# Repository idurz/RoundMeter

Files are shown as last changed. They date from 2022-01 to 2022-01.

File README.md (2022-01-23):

# RoundMeter
CO2 measurement as a learning experiment with a round LCD. The device will show succesively a (dutch) weather forecast. the CO2 measurement in the room and a (dutch) forecast for the rain amount the next 2 hours.

## PARTS USED
- Waveshare 1.28 Round LCD
- Winsen MH-Z19B CO2 sensor 
- Wemos D1 mini lite ESP8266 micro controller
- USB micro cable connected to a power source

## Information sources
Thanks to the Dutch website Buienradar.nl which has the weather conditions in JSON format and a text based rain forecast for the next 2 hours. The CO2 information is read fromt he local MHZ sensor.

**Note:** The sensor is intended for the Dutch weather forecast. You can reuse parts and ideas for the rest of the world, change urls and interpretation of the output in the way you like.

## Build
### Connect CO2 Sensor
The Winsen CO2 sensor has a break-out board. From that board you need to connect four cables to the Wemos board:
- Green (RX) to Wemos D1
- Blue (TX) to Wemos D2
- Black (Gnd) to Wemos GND _(shared with display)_
- Red (5V) to Wemos 5V _(shared with display)_

### Connect Display
The WaveShare 1.18 Inch LCD display uses a SPI interface. Connect the following wires to the Wemos board:
- Blue (DC) to Wemos D3
- Yellow (CS) to Wemos D0
- Orange (CLK) to Wemos D5
- Green (DIN) to Wemos D7
- Purple (VCC) to Wemos 3V3
- White (GND) to Wemos GND _(shared with sensor)_
- Grey (BL) to Wemos 5V _(shared with sensor)_
- Brown (RST) to Wemos D4

### The Box
The box is designed with [TinkerCad](https://www.tinkercad.com/things/4qZ85xxE9la-128-round-lcd-2). Download or change the box there, or simply download the STL file from the /box design directory.

### Software
I used Visual Studio Code with the Platform IO extension to create and upload the code to the Wemos. It will work with e.g. the Arduino editor as well, but you might need to change some library references etc.

### Localization
Check the main.ccp file. On line 178 in the variable rain_link2 the latitude and longitude of the rain forecast location is mentioned. Change to a convineant lcation.
Also on line 179 the station id is mentioned for the Weather station. If you want to know alternatives, view the [JSON info](data.buienradar.nl/2.0/feed/json) online. Change to what fits you best.

Recompile the source and upload to the Wemos.

## INSTALLATION
This device is using the wifimanager library for an initial setup in a new environment. Power up the meter the first time in a new environment and give it some moments to start up. The device will create a Wifi network with the SSID "Kippenhok".

- Go to the settings on your phone
- Select the netwerk "Kippenhok"
- Your phone will connect to the network "Kippenhok"
- A webpage will pop-up automatic
- Select "Configure Wifi" 
- Select your own network in the list
- Add the password for this network
- Confirm

The Co2 meter device will now restart automatic and connect to the network you selected above. If this does not work for some reason, you need to repeat the Installation steps.

## OPERATIONAL

The meter will announce itself during boot phase. After that, the screen will refresh every 10 seconds witht he next screen.(see define SCREEN_CHANGE_TIMEOUT if you want to change that)
1. The Weather info screen will tell you some important weather parameters.
2. The CO2 info screen will tell you the current CO2 value. The outter ring will be green between 0 and 800, yellow between 800-1200 and red above 1200.
3. The rain info screen shows the amount of rain expected for the next 2 hours, in blocks of 10 minutes. The graph will be blue if the maximum expected rain is less than 5 mm/hour. If the maximum amount of rain is above 5 mm/hour and below 20 mm/hour than the graph will be in the magenta color. Above 20 mm/hour the graph will be shown in red.

If the meter is not working as intended connect an USB cable to a serial terminal. Use the Arduino terminal, or the built-in one in PlatformIO and read what is happening. Every step the Wemos makes is written to the console. Perhaps it gives you a clue what is happening.

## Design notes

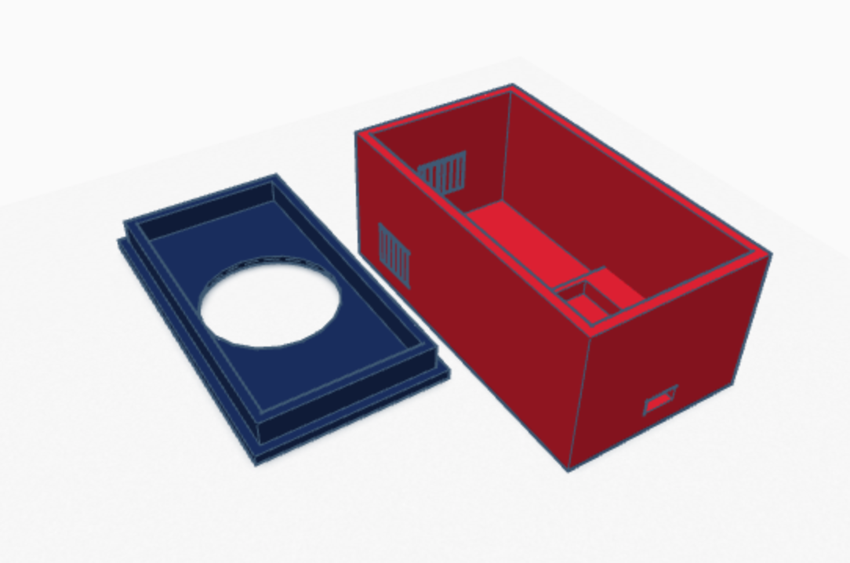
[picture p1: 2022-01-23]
box design/3d view.png

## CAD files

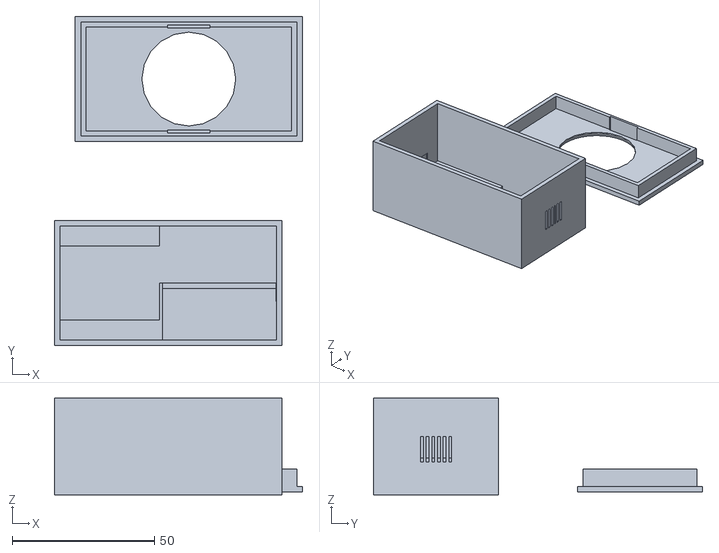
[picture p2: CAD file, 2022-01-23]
box design/1.28 round LCD #2-2.stl
87.2 x 115.7 x 34.0

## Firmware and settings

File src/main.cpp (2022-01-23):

/* *****************************************************************************

   Copyright (C) 2022 P.A.G.M. Zengers

   This program shows weather and environmental information a a round 
   LCD screen. The weather information is intended for the Netherlands. 
   You can select the info via a potmeter hoe heet zon ding

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
   You can find my contact details at <https://github.com/idurz/>

   Environment       : PlatformIO
   Settings          : platform = espressif8266
                     : board = d1_mini_lite
                     : framework = arduino
                      +-----------------------------+
                      |                             |
                      |     +--------------------+  |
   +---------+        |     |    WEMOS D1 MINI   |  |
   |WAVESHARE|        |     |                    |  |       +---------+
   |         |        |     ()rst RST         TX()  |       | MHZ-19B |
   |     DC ()-blue---+     ()A0 ADC0         RX()  |       |         |
   |     CS ()-yellow-------()D0 WAKE     SCL D1()--|green--()RX      |
   |    CLK ()-orange-------()D5 SCLK     SDA D2()--|blue---()TX      |
   |         |              ()D6 MISO   FLASH D3()--+       |         |
   |    DIN ()-green--------()D7 MOSI         D4()--------+ |         |
   |         |              ()D8 CS          GND()-+-black|-()GND     |
   |    VCC ()-purple-------()3V3             5V()-|-red+-|-()5V      |
   |    GND ()-white-----+  +--------------------+ |    | | +---------+
   |     BL ()-grey----+ |                         |    | |
   |    RST ()-brown-+ | +-------------------------+    | | 
   +---------+       | +--------------------------------+ |  
                     +------------------------------------+
 * ****************************************************************************/


/* *****************************************************************************
   Include the necessary libraries here
 * *****************************************************************************/

#include <Arduino.h>
#include <ESP8266WiFi.h>          // https://github.com/esp8266/Arduino
#include <DNSServer.h>            // needed for library above
#include <ESP8266WebServer.h>
#include <WiFiManager.h>          // https://github.com/tzapu/WiFiManager
#include <TFT_eSPI.h>             // Include the graphics library (incl sprite)
#include <SoftwareSerial.h>
#include <MHZ19.h>
#include "WeatherSymbols.h"       // Our pictures in a C array

/* *****************************************************************************
   Defines, to ensure our code is easier to maintain
 * ****************************************************************************/

#define VERSION                   "1.0.0"

// ip based
#define DEVICE_NAME               "Kippenhok" // Name in station mode

// Pin mapping
#define PIN_D0                     16
#define PIN_D1                     5
#define PIN_D2                     4
#define PIN_D3                     0
#define PIN_D4                     2
#define PIN_D5                     14
#define PIN_D6                     12
#define PIN_D7                     13
#define PIN_D8                     15
#define PIN_D9                     3
#define PIN_D10                    1

// Serial port config
#define DEBUG_OUTPUT_BAUDRATE      9600  // Hardware serial (USB)
#define SENSOR_OUTPUT_BAUDRATE     9600  // Software serial

// Screen definitions
#define SCREEN_CHANGE_TIMEOUT      10000 // ms to wait before showing another screen
#define SCREEN_WEATHER             1     // ID for Show_Weather info
#define SCREEN_CO2                 2     // ID for Show_CO2 info
#define SCREEN_RAIN                3     // ID for Show_CO2 info
#define SCREEN_COUNT               3     //  screens available

#define RESET_DELAY_ON_ERROR       15000 // (ms) delay after panic to ensure last message is read
#define ESTABLISH_DELAY            500   // (ms) delay after important tasks to settle down

#define JSON_INTERVAL_SEC          600   // Interval time (sec) between for retrieving weather info
#define RAIN_INTERVAL_SEC          600   // Interval time (sec) between for retrieving buienradar info
#define CO2_INTERVAL_SEC           5     // Interval time (sec) between for retrieving CO2 info

#define HTTPS_TIMEOUT_SEC          15    // (sec) timeout for https call

#define TEXT_SIZE_SMALL            1     // 16 pixels high
#define TEXT_SIZE_MEDIUM           2     // 26 pixels high
#define TEXT_SIZE_LARGE            4     // 48 pixels high
#define TEXT_SIZE_XLARGE           6
#define TEXT_MAX_LENGTH            30

#define SYMBOL_WIDTH               50
#define SYMBOL_HEIGTH              50

// Meter colour schemes
#define RED2RED                    0
#define GREEN2GREEN                1
#define BLUE2BLUE                  2
#define BLUE2RED                   3
#define GREEN2RED                  4
#define RED2GREEN                  5
#define THREECOLOR                 6

// Set the the position and inner radius of the CO2 meter
#define METER_XPOS                 0
#define METER_YPOS                 0
#define METER_RADIUS               120
#define METER_MINVALUE             0
#define METER_MAXVALUE             2400

// Position info for the rain graph
#define RAIN_TOPX                  40
#define RAIN_TOPY                  40
#define RAIN_XLEN                  161
#define RAIN_YLEN                  160
#define RAIN_READINGS 24

/* MHZ Error codes  0   NULL, Library logic error, should not occur
                    1   OK
                    2   Timeout waiting for response
                    3   Syntax error in received data
                    4   CRC error in received data
                    5   Filter kicked in (value within 30 seconds of reset)
                    6   Failed   */

/* *****************************************************************************
   Global variables out of scope of functions
 * *****************************************************************************/
int                  MHZ_CO2,            // CO2 value of MHZ
                     MHZ_Temp;           // Indoor temp from MHZ

String               MHZ_Error,          // Last error message from MHZ
      	             WTH_timestamp,      // "2022-01-02T12:30:00",
		                 WTH_description,    // "Zwaar bewolkt",
                     WTH_icon,           // "https://www.buienradar.nl/resources/images/weather/30x30/c.png"
                     WTH_winddirection,  // "ZW",
                     WTH_sunrise,
                     WTH_sunset,
                     WTH_error,
                     WTH_airpressure,    // 1010.4,
		                 WTH_temperature,    // 12.3,
	                   WTH_windspeed,      // 5.7,
		                 WTH_humidity,       // 83.0,
			               WTH_precipitation,  // 0.0,
			               WTH_sunpower,       // 61.0,
			               WTH_rainFallLast24Hour, // 3.9,
			               WTH_rainFallLastHour; // 0.0,

String               RAIN_error;
float                Rain[RAIN_READINGS];         // Rain forecast in mm/hour
float                Rain_max;

// Weather data
const char*          json_host = "data.buienradar.nl";
const char*          json_link = "/2.0/feed/json";
unsigned long        json_next_get = 0;
const char*          rain_host = "gpsgadget.buienradar.nl";
const char*          rain_link1 = "/data/raintext?";
const char*          rain_link2 = "lat=52.14&lon=5.58"; 
String               stationid = "\"stationid\":6260";
unsigned long        rain_next_get = 0;
int                  screen_to_show =0; 

WiFiClientSecure httpsClient; // https://github.com/espressif/arduino-esp32/tree/master/libraries/WiFiClientSecure
SoftwareSerial   sensor(PIN_D1, PIN_D2); //rx, tx
MHZ19            mhz(&sensor); 
TFT_eSPI         tft = TFT_eSPI();  // Create object "tft"

unsigned int rainbow(byte value) {
/* *************************************************************************************************
   rainbow

   Return a 16 bit rainbow colour
 * *************************************************************************************************/

  // Value is expected to be in range 0-127
  // The value is converted to a spectrum colour from 0 = red through to 127 = blue

  byte red   = 0; // Red is the top 5 bits of a 16 bit colour value
  byte green = 0;// Green is the middle 6 bits
  byte blue  = 0; // Blue is the bottom 5 bits

  byte sector = value >> 5;
  byte amplit = value & 0x1F;

  switch (sector)
  {
    case 0:
      red   = 0x1F;
      green = amplit;
      blue  = 0;
      break;
    case 1:
      red   = 0x1F - amplit;
      green = 0x1F;
      blue  = 0;
      break;
    case 2:
      red   = 0;
      green = 0x1F;
      blue  = amplit;
      break;
    case 3:
      red   = 0;
      green = 0x1F - amplit;
      blue  = 0x1F;
      break;
  }
  return red << 11 | green << 6 | blue;

}

void ringMeter(int value, int vmin, int vmax, int x, int y, int r, String units, int scheme) {
/* *************************************************************************************************
   ringMeter

   Draw the meter on the screen, returns x coord of righthand side
 * *************************************************************************************************/
  // Minimum value of r is about 52 before value text intrudes on ring
  // drawing the text first is an option
  
  x += r; y += r;   // Calculate coords of centre of ring

  // int w = r / 4;    // Width of outer ring is 1/4 of radius
  int w = r / 6;    // Width of outer ring is 1/6 of radius
  
  int angle = 150;  // Half the sweep angle of meter (300 degrees)

  int text_colour = 0; // To hold the text colour

  int v = map(value, vmin, vmax, -angle, angle); // Map the value to an angle v

  byte seg = 5; // Segments are 5 degrees wide = 60 segments for 300 degrees
  byte inc = 5; // Draw segments every 5 degrees, increase to 10 for segmented ring

  // Draw colour blocks every inc degrees
  for (int i = -angle; i < angle; i += inc) {

    // Choose colour from scheme
    int colour = 0;
    switch (scheme) {
      case 0: colour = TFT_RED; break; // Fixed colour
      case 1: colour = TFT_GREEN; break; // Fixed colour
      case 2: colour = TFT_BLUE; break; // Fixed colour
      case 3: colour = rainbow(map(i, -angle, angle, 0, 127)); break; // Full spectrum blue to red
      case 4: colour = rainbow(map(i, -angle, angle, 63, 127)); break; // Green to red (high temperature etc)
      case 5: colour = rainbow(map(i, -angle, angle, 127, 63)); break; // Red to green (low battery etc)
      case 6: if (i < -50) colour = TFT_GREEN; 
              else if (i < 0) colour = TFT_YELLOW;
                    else colour = TFT_RED;
              break;
      default: colour = TFT_BLUE; break; // Fixed colour
    }

    // Calculate pair of coordinates for segment start
    float sx = cos((i - 90) * 0.0174532925);
    float sy = sin((i - 90) * 0.0174532925);
    uint16_t x0 = sx * (r - w) + x;
    uint16_t y0 = sy * (r - w) + y;
    uint16_t x1 = sx * r + x;
    uint16_t y1 = sy * r + y;

    // Calculate pair of coordinates for segment end
    float sx2 = cos((i + seg - 90) * 0.0174532925);
    float sy2 = sin((i + seg - 90) * 0.0174532925);
    int x2 = sx2 * (r - w) + x;
    int y2 = sy2 * (r - w) + y;
    int x3 = sx2 * r + x;
    int y3 = sy2 * r + y;

    if (i < v) { // Fill in coloured segments with 2 triangles
      tft.fillTriangle(x0, y0, x1, y1, x2, y2, colour);
      tft.fillTriangle(x1, y1, x2, y2, x3, y3, colour);
      text_colour = colour; // Save the last colour drawn
    }
    else // Fill in blank segments
    {
      tft.fillTriangle(x0, y0, x1, y1, x2, y2, TFT_LIGHTGREY);
      tft.fillTriangle(x1, y1, x2, y2, x3, y3, TFT_LIGHTGREY);
    }
  }

  // Set the text colour
  tft.setTextColor(text_colour, TFT_BLACK);
  
  // Print value, if the meter is large then use big font 6, othewise use 4
  if (r > 84) tft.drawCentreString(" " + String(value) + " ", x - 5, y - 20, TEXT_SIZE_XLARGE); // Value in middle
  else tft.drawCentreString(" " + String(value) + " ", x - 5, y - 20, TEXT_SIZE_LARGE); // Value in middle

  // Print units, if the meter is large then use big font 4, othewise use 2
  tft.setTextColor(TFT_WHITE, TFT_BLACK);
  if (r > 84) tft.drawCentreString(units, x, y + 30, TEXT_SIZE_LARGE); // Units display
  else tft.drawCentreString(units, x, y + 5, TEXT_SIZE_MEDIUM); // Units display
}

void configModeCallback (WiFiManager *myWiFiManager) {
/* *************************************************************************************************
   Wifi Connect Manager

   From the WifiManager library. Will be called when in station mode. Gives it
   the opportunity to inform the user or do other things
 * *************************************************************************************************/
  Serial.println(F("Station mode; My ip:"));
  Serial.println(WiFi.softAPIP());
  Serial.println("SSID: " + String(myWiFiManager->getConfigPortalSSID()));

  //tft.setCursor( 0, 12); tft.print("Station mode; My ip:");
  //tft.setCursor( 0, 24); tft.print(WiFi.softAPIP());
  //tft.setCursor( 0, 36); tft.print(MSG_SSID);
  //tft.print(myWiFiManager->getConfigPortalSSID());

}

float mmHour(int radarvalue) {
/* *************************************************************************************************
   mmHour

   Calculate the rain fall in mm/hour by using the values from buienradar and their logaritmic type
   of scale like this 10^((value -109)/32) (example: 77 = 0.1 mm/hour)
 * *************************************************************************************************/
  return (pow(10, (radarvalue - 109) / 32.0) * 10.0) / 10.0;
}

void Show_Rain() {
  /* *************************************************************************************************
   Show_Rain

   Gets the global saved rain info fetched from the URL and displays on the TFT screen
 * *************************************************************************************************/

  Serial.println(F("Executing Show_Rain"));
  tft.startWrite();
  tft.fillScreen(TFT_BLACK); // Clear the screen first

  // Top level info

  tft.setTextColor(TFT_SKYBLUE);
  tft.setTextSize(TEXT_SIZE_SMALL);
  tft.drawCentreString(String(WTH_rainFallLast24Hour) + " mm",METER_RADIUS,15,TEXT_SIZE_SMALL);
  tft.drawCentreString("Laatste 24 uur",METER_RADIUS,27,TEXT_SIZE_SMALL);
  
  // Bottom text
  tft.setTextColor(TFT_SKYBLUE);
  tft.drawCentreString("Regen komende 2 uur",METER_RADIUS,210,TEXT_SIZE_SMALL); // Value in middle
  tft.drawCentreString("BuienRadar.nl",METER_RADIUS,220,TEXT_SIZE_SMALL); // Value in middle


  //Rain_max = 4; // for testing


  // If there is no rain expected, don't bother printing, but give a simple message and return
  if (Rain_max < 0.01) {
    tft.setCursor(10, 118);
    tft.setTextSize(TEXT_SIZE_MEDIUM);
    tft.print("Geen regen voorzien");
    tft.setCursor(10, 140);
    tft.print("  komende twee uur");
   
    tft.drawLine(105,230,135,230,TFT_MAROON);
    for (int j=0;j<(SCREEN_CHANGE_TIMEOUT / 1000);j++) {
      delay(1000);
      tft.drawPixel(105+(j*3),230,TFT_SKYBLUE);
      tft.drawPixel(105+1+(j*3),230,TFT_SKYBLUE);
    }
    Serial.println(F("Completed Show_Rain"));
    return;
  }

  // Arriving here, we not that it will rain coming 2 hours
  // Make fixed definitions of 5 and 20 mm or higher if it is really wet
  int bar_color = TFT_RED;
  if (Rain_max <= 5) {
    Rain_max = 5;
    bar_color = TFT_BLUE;
  } else {
    if (Rain_max <= 20) {
      Rain_max  = 20;
      bar_color = TFT_MAGENTA;
    } else {
      Rain_max = 100;
    }
  }

  // Calculate the value for the two reference lines
  float lowline = round(Rain_max * 10 / 3) / 10;  // at 1/3 of graph
  float highline = round(Rain_max * 20 / 3) / 10; // at 2/3 of graph

  // Draw graph border
  tft.drawRect(RAIN_TOPX-1,RAIN_TOPY-1,RAIN_XLEN+1,RAIN_YLEN+2,TFT_NAVY);

  // We have 0..23 values; every 7 dots we need to print a new one. 
  // Also we need to fill the intermediate ones. total using 161 dots
  int x_axes = 40;
  int y_len, y_len_next;
  for (int moment = 0; moment < RAIN_READINGS-1; moment++) {

    // Lets set the first dot to start with
    y_len      = int(RAIN_YLEN - Rain[moment] / Rain_max * RAIN_YLEN) + RAIN_TOPY;
    y_len_next = int(RAIN_YLEN - Rain[moment+1] / Rain_max * RAIN_YLEN) + RAIN_TOPY;
   
    for (int j = 0; j <  7; j++) {
      int intermediate_bar = int((y_len_next - y_len) * j/7) + y_len;
      //Serial.println("xas: " + String(x_axes) + "; m: "  + String(Rain[moment]) + ";" + String(Rain[moment+1]) +
      //             " ylen:" + String(y_len) + ";" + String(y_len_next) + "; j:" + String(j) +
      //             "  int:" + String(intermediate_bar));
      tft.drawLine(x_axes,RAIN_TOPY + RAIN_YLEN,x_axes,intermediate_bar,bar_color);
      yield(); // give me a break
      x_axes++; // next pixel
    }  // for all intermediate steps
  } // for all 23 measurements

  // Finally print the lines for the reference values
  tft.drawLine(RAIN_TOPX
              ,int(RAIN_YLEN/3+RAIN_TOPY)
              ,RAIN_TOPY+RAIN_YLEN
              ,int(RAIN_YLEN/3+RAIN_TOPY)
              ,TFT_WHITE);   // top line
  tft.drawLine(RAIN_TOPX
              ,int(2*RAIN_YLEN/3+RAIN_TOPY)
              ,RAIN_TOPY+RAIN_YLEN             
              ,int(2*RAIN_YLEN/3+RAIN_TOPY)
              ,TFT_WHITE); // bottom line

  // and write the text for the reference value on it
  tft.setTextColor(TFT_SKYBLUE);
  tft.setTextSize(TEXT_SIZE_SMALL);
  tft.drawString(String(int(lowline)) + " mm/h",5,int(2*RAIN_YLEN/3+RAIN_TOPY));
  tft.drawString(String(int(highline)) + " mm/h",5,int(RAIN_YLEN/3+RAIN_TOPY));

  tft.drawLine(105,230,135,230,TFT_MAROON);
  for (int j=0;j<(SCREEN_CHANGE_TIMEOUT / 1000);j++) {
    delay(1000);
    tft.drawPixel(105+(j*3),230,TFT_SKYBLUE);
    tft.drawPixel(105+1+(j*3),230,TFT_SKYBLUE);
  }
  tft.endWrite();
  Serial.println(F("Completed Show_Rain"));
}

void Get_CO2() {
/* *****************************************************************************
   Get_CO2

   Retrieve info from the MHZ19b sensor
 * *****************************************************************************/ 
  Serial.println(F("Executing Get_CO2")); 
  MHZ19_RESULT MHZ_Error = mhz.retrieveData();
  
  MHZ_CO2 = 0; // reset to zero to ensure we have the latest values
  MHZ_Temp = 0;

  if (MHZ_Error == MHZ19_RESULT_OK) {
    MHZ_CO2 = mhz.getCO2();
    MHZ_Temp = mhz.getTemperature();
  } else {
    Serial.print(F("Reading from MHZ19B Sensor failed; error code: "));
    Serial.println(MHZ_Error);
  }
  Serial.println(F("Completed Get_CO2"));
}

void Show_CO2() {
/* *************************************************************************************************
   Show_CO2

   Displays CO2 info on screen
 * *************************************************************************************************/
  Serial.println(F("Executing Show_CO2"));
  tft.startWrite(); 
  tft.fillScreen(TFT_BLACK);
  tft.drawLine(105,230,135,230,TFT_MAROON);
  tft.setTextSize(TEXT_SIZE_SMALL);

  for (int j=0;j<(SCREEN_CHANGE_TIMEOUT / 1000);j++) {
    Get_CO2(); 
    yield(); // give me a break
    ringMeter(MHZ_CO2, METER_MINVALUE, METER_MAXVALUE,
              METER_XPOS, METER_YPOS, METER_RADIUS,"CO2",THREECOLOR); // Draw analogue meter 
    delay(1000); 

    tft.drawPixel(105+(j*3),230,TFT_SKYBLUE);
    tft.drawPixel(105+1+(j*3),230,TFT_SKYBLUE);
  }
  tft.endWrite();
  Serial.println(F("Completed Show_CO2"));
}
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
void loop() {
/* *****************************************************************************
   loop

   Keep doing this until we loose power
 * *****************************************************************************/

  // Do we need to fetch new info?
  if (json_next_get < millis()) {
    Get_Weather(); 
    json_next_get = millis() + (JSON_INTERVAL_SEC * 1000);
  } 
  if (rain_next_get < millis()) {
    Get_Rain(); 
    rain_next_get = millis() + (RAIN_INTERVAL_SEC * 1000);
  } 

  // Decide which screen to show
  screen_to_show++;
  if (screen_to_show > SCREEN_COUNT) screen_to_show = 1;

  if (screen_to_show == SCREEN_WEATHER) Show_Weather();
  if (screen_to_show == SCREEN_RAIN)    Show_Rain();
  if (screen_to_show == SCREEN_CO2)     Show_CO2();
}

/* *****************************************************************************
   FINISH
 * *****************************************************************************/
 

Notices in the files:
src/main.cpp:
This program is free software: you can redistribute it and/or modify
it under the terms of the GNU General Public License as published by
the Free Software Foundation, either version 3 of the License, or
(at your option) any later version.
